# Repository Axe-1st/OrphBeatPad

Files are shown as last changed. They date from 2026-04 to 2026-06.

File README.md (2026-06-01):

# OrphBeatPad - A custom/open source Beat pad with awesome design!
## V2 IS OUT!! 
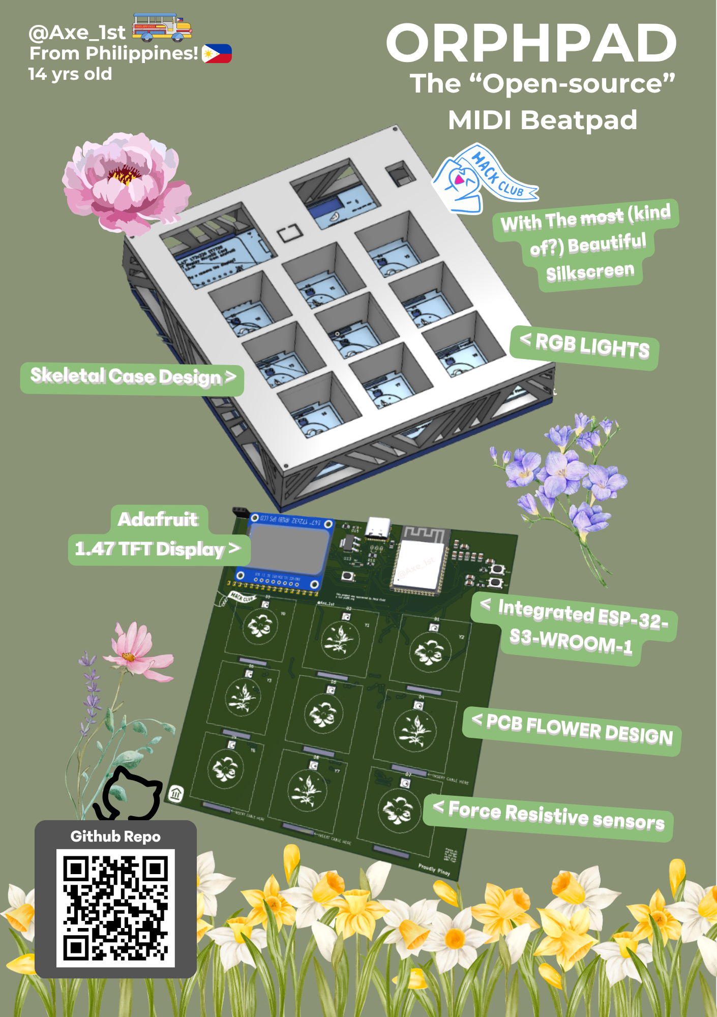
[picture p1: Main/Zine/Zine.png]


> PDF is available in Zine folder!

#### I wanted to make an custom beat pad that you can plug in into your computer and its good to go!
#### I would say the motivation was discovering FRS Sensors and bc i love hardware too much.
#### It Exists since i want to get started with making MIDI Stuff and see how much it can cost!
#### This project is basicaly a beat pad that can sense how hard are you tapping the pads and, BUT the most special part about this is it has integrated esp32-s3-wroom 1 🫣

#### Notes:
- The FSR Sensors Does not use a breakout board!
- There are Silicon pads that i will have to invividualy place to act as buttons!
- we will be ussing flush cutters so we can fit things nicely!
- We will use a combination of reflow and manual soldering.

### Schematic

#### New Schematic


### PCB 
#### look at that pcb 🤤

#### New PCB Design


### "pcb render"

#### New Version



- couldn't find a FSR sensor thats bent sorry!

### CAD


### Onshape Link https://cad.onshape.com/documents/ce0d6d23ca34879564001471/w/3b900ad8676028993156f6d1/e/086cec854ef049c97401a80d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

#### i love onshape man

## How to build it
### a project thats been wating to be funded so it will relese soon!
#### But don't worry i can give you a rough idea how to make it!

- Step 1 Make sure all of your materials are ready such as (PCB, Stencil, Compoments, Hot Plate, 3D printed Case) if not don't worry as you can buy the compoments online from digikey and Jlcpcb! Check the BOM cause it has links!

- Step 2 Align the Stencil and spread solder Paste

- Step 3 Gently remove the stencil then place all of your compoments to reflow it at the hot plate! (you can use a soldering iron if you think you can do it!) a little tip when placing start from smallest to biggest!\

- Step 4 Reflow the board by making sure that the esp32 is in the middle! 

- Step 5 Now the Reflow is done start adding the compoments that need manual hand soldering, such as: Sk-mini-e, 16 channel Swicher, FSR sensor pads.

- Step 6 Your PCB is assembled! Final step is to assemble with the case! To assemble the case (3 parts) get the bottom and middle super glue it, then after drying place the pcb inside, also make sure the external pins are cut with a flush cutter! Add the top case then superglue it or Use any M4 thread screw.

- Step 7 Cut the Silicon Sheet into squares boxes then place it where the FSR Sensor holes are!

- Final step is to Plug in the USB C cable and hope no smoke comes out.. If none good job! Flash it with the firmware i have provided :)

- And thats your own OrphBeatpad! Enjoy tinkering with it!!

## Bill of materials
### check Bom.csv

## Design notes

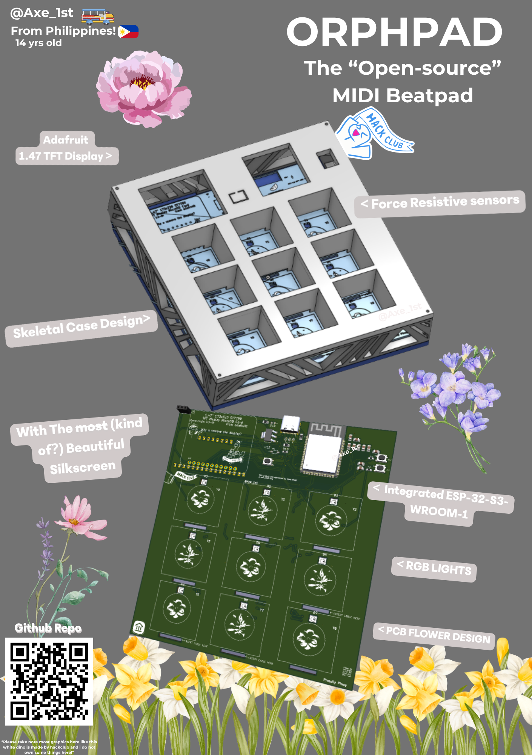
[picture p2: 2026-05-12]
Main/Zine/Orphpad Zine final (1).png

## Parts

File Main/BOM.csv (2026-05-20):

Product | Link | Quantity | Price USD | total
ESP32-S3-WROOM-1 | https://jlcpcb.com/partdetail/3198295-ESP32_S3_WROOM_1N4/C2913197 | 1 | $4.49 | $4.49
Silicon sheet | Translucent Silicone Rubber Sheet Plate Mat High Temperature Resistant Clear Gasket Thick 0.5 1 2 3 4 5mm | Shopee Philippines | 1 | $1.64 | $1.64
LESD5D5.0CT1G | https://jlcpcb.com/partdetail/LRC-LESD5D50CT1G/C383211 | 10 | $0.40 | $4.00
1N5819HW-7-F | https://jlcpcb.com/partdetail/DiodesIncorporated-1N5819HW_7F/C82544 | 2 | $0.04 | $0.08
FSR Sensors | https://shopee.ph/FSR402-RFP602-Resistive-Thin-Film-Pressure-Sensor-Module-Force-Sensitive-Resistor-Board-RFP602-1KG-2KG-5KG-Weighing-Voltage-Conversion-Modul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 | 1 | $19.62 | $19.62
16 channel switcher | https://shopee.ph/CD74HC4067-16-Channel-Analog-Digital-Multiplexer-Breakout-Board-Module-For-Arduino-i.266699902.22751563093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 | 1 | $1.07 | $1.07
SK-Mini-e | https://jlcpcb.com/partdetail/OPSCOOptoelectronics-SK6812MINIE/C5149201 | 20 | $0.09 | $1.80
C2912598 | https://jlcpcb.com/partdetail/C2912598 | 5 | $0.08 | $0.40
Resistor | https://jlcpcb.com/partdetail/RESI-PTFR0805B200RP9/C2849095 | 5 | $0.07 | $0.35
Type C female | https://jlcpcb.com/parts/componentSearch?searchTxt=C2765186 | 1 | $0.09 | $0.09
JLCPCB | JLCPCB | 1 | $9.50 | $9.50
10uf cap | https://www.digikey.ph/en/products/detail/samsung-electro-mechanics/CL21A106KAYNNNG/3894413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 | 10 | $0.09 | $0.89
1uf capacitor | https://www.digikey.ph/en/products/detail/samsung-electro-mechanics/CL10A105KO8NNNC/3886692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 | 5 | $0.10 | $0.50
10 ohm resistor | https://www.digikey.ph/en/products/detail/stackpole-electronics-inc/RNCP0603FTD10K0/2240139 | 10 | $0.01 | $0.12
CAP CER 0.1UF 50V X7R 0603 | https://www.digikey.ph/en/products/detail/samsung-electro-mechanics/CL10B104KB8NNNL/3894274 | 12 | $0.03 | $0.32
4518-AMS1117-3.3TR-ND | https://www.digikey.ph/en/products/detail/umw/AMS1117-3-3/17635254 | 3 | $0.30 | $0.90
399-C0603C220J5GAC7867TR-ND | https://www.digikey.ph/en/products/detail/kemet/C0603C220J5GACTU/411055 | 3 | $0.13 | $0.39
smd Buttons | https://www.digikey.ph/en/products/detail/c-k/PTS810SJG250SMTR-LFS/4176612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 | 6 | $0.60 | $3.60
Pwr led | https://www.digikey.ph/en/products/detail/liteon/LTST-C190TBKT/388529?s=N4IgTCBcDaIIwDYAMBaRAWBKwoHIBEQBdAXyA | 2 | $0.17 | $0.34
Soldering hot plate | https://shopee.ph/G3061-PD65W-Mini-Hot-Plate-Digital-Soldering-Preheating-Rework-Station-PCB-SMD-Board-Soldering-Plate-Heating-Table-i.1118934132.29593809780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 | 1 | $11.46 | $11.46
Adafruit 1.47 tft | https://www.digikey.ph/en/products/detail/adafruit-industries-llc/5393/16129670 | 1 | $17.50 | $17.50
Stencil | JLCPCB | 1 | $7.90 | $7.90
 |  |  |  | TOTAL
 |  |  |  | $86.96

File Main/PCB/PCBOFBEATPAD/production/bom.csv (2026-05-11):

Designator | Footprint | Quantity | Value | LCSC Part #
C1, C2, C4, C9 | 0805 | 4 | 10uF
C10 | 0805 | 1 | 1uF
C3, C5, C6, C7, C8 | 0805 | 5 | 0u1F
D1, D2, D3, D4, D5, D6, D7, D8, D9 | SK6812MINI-E_fixed | 9 | SK6812MINI-E
D10, D12, D13 | TVS_LESD5D5.0CT1G | 3 | LESD5D5.0CT1G
D11 | SOD3715X145N | 1 | 1N5819HW-7-F
D15 | LEDC1608X35N | 1 | LTST-C190KGKT
J1 | HRO_TYPE-C-31-M-12 | 1 | TYPE-C-31-M-12
J3 | PinSocket_1x03_P2.00mm_Vertical | 1 | Conn_01x03
JP1 | 1X11_ROUND_76 | 1 | ~
R1, R10, R13, R14, R15, R2, R3, R4, R5, R6, R7, R8 | 0603 | 12 | 10k
R11, R9 | 0805 | 2 | 5k1
R12 | 0805 | 1 | 75
SW1, SW2, SW3 | SW_PTS810_SJM_250_SMTR_LFS | 3 | PTS810_SJM_250_SMTR_LFS
U1, U10, U11, U3, U5, U6, U7, U8, U9 | 2 pin connector | 9 | ~
U12 | XCVR_ESP32-S3-WROOM-1-N16R2 | 1 | ESP32-S3-WROOM-1-N16R2
U13 | SOT229P700X180-4N | 1 | AMS1117-3.3
U2 | analog_16_multiplexer_module | 1 | ~

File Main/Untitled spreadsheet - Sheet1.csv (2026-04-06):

Product | Link | Price PHP | Price USD | Current USD Price
ESP32-C3 DEVBOARD | https://shopee.ph/ESP32-SuperMini-Development-Board-ESP32-C3-ESP32-S3-ESP32-C6-ESP32-H2-Development-Board-ESP32-Development-Board-WiFi- | $130.00 | $2.15 | 60.41
Silicon sheet | Translucent Silicone Rubber Sheet Plate Mat High Temperature Resistant Clear Gasket Thick 0.5 1 2 3 4 5mm | Shopee Philippines | $100.00 | $1.66 | 60.41
SK MINI 6812 1 SET | https://shopee.ph/10PCS-SK6812-MINI-E-RGB-(Similar-WS2812B)-SK6812-3228-SMD-Pixels-LED-Chip-Individually-Addressable-i.672422012.12275127933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 | $30.00 | $0.50 | 60.41
Connector | https://shopee.ph/2.54MM-R-A-Double-Row-Female-2~40P-PCB-Board-Right-Angle-Pin-Header-Socket-Connector-Pinheader-2*-4-6-10-20-40-Pin-For-Arduino-i.1130255612.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 | $69.00 | $1.14 | 60.41
Force resistive sensors | https://shopee.ph/FSR402-RFP602-Resistive-Thin-Film-Pressure-Sensor-Module-Force-Sensitive-Resistor-Board-RFP602-1KG-2KG-5KG-Weighing-Voltage-Conversion-Modul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 | $1,197.00 | $19.81 | 60.41
16 channel switcher | https://shopee.ph/CD74HC4067-16-Channel-Analog-Digital-Multiplexer-Breakout-Board-Module-For-Arduino-i.266699902.22751563093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 | $65.00 | $1.08 | 60.41
1.3 tft | https://shopee.ph/TFT-Display-0.96-1.3-1.44-Inch-IPS-7P-SPI-HD-65K-Full-Color-LCD-Module-ST7735-Drive-IC-80*160-(Not-OLED)-For-Arduino-i.580325202.13990205071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 | $128.00 | $2.12 | 60.41
JLCPCB |  | $0.00 | $5 | 60.41
 |  | $0.00 | $0.00 | 60.41
 |  | $0.00 | $0.00 | 60.41
 |  | $0.00 | $0.00 | 60.41

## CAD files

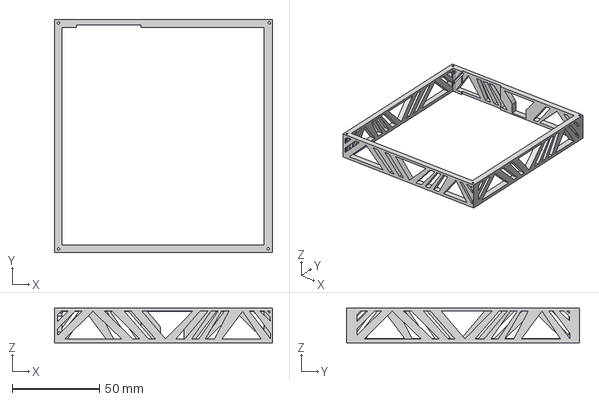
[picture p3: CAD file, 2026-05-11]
Main/CAD/Middle.step
124.7 x 133.4 x 20.0 mm

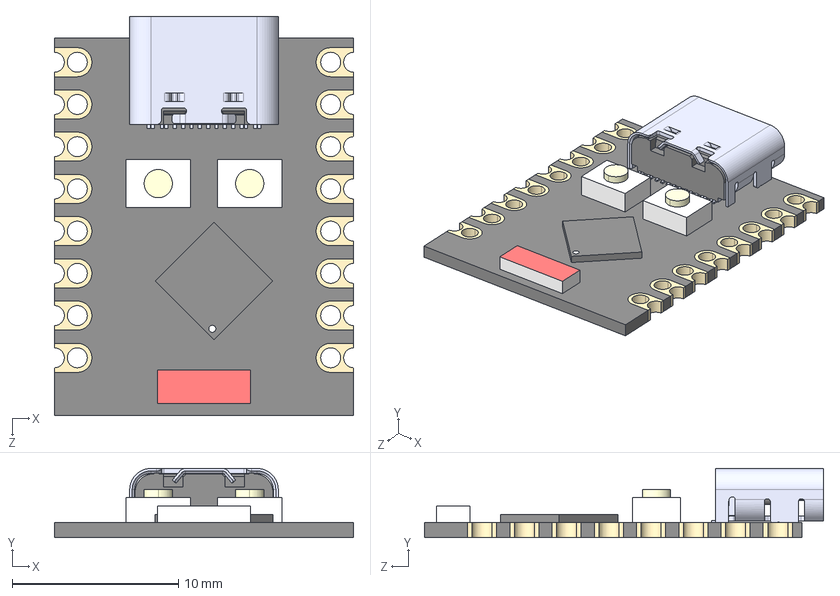
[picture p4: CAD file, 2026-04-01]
Main/EXTRAS/ESP32-C3_SUPERMINI_TH/ESP32-C3_SUPERMINI_TH.step
18.0 x 4.16 x 24.0 mm
Board c3mini
USB C
components (other)^ESP32-C3 SuperMini

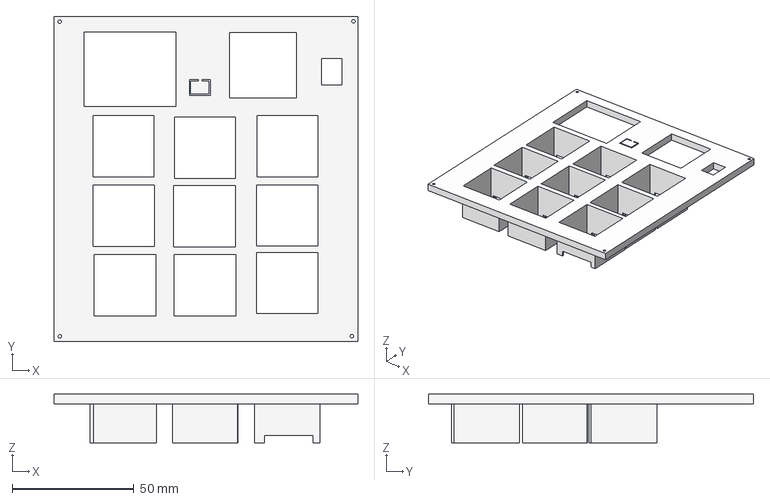
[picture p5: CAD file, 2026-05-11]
Main/CAD/Top.step
124.7 x 133.4 x 20.0 mm

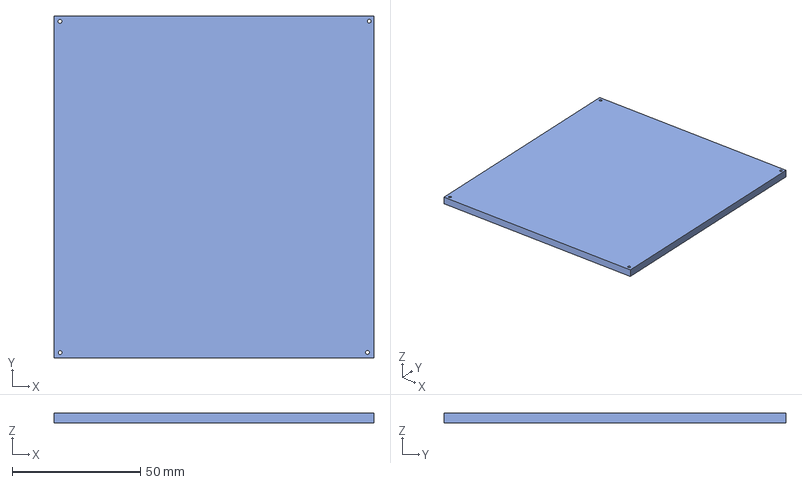
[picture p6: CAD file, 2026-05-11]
Production/Bottom.step
124.7 x 133.4 x 4.00 mm

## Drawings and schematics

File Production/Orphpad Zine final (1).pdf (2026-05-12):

# The “Open-source” MIDI Beatpad

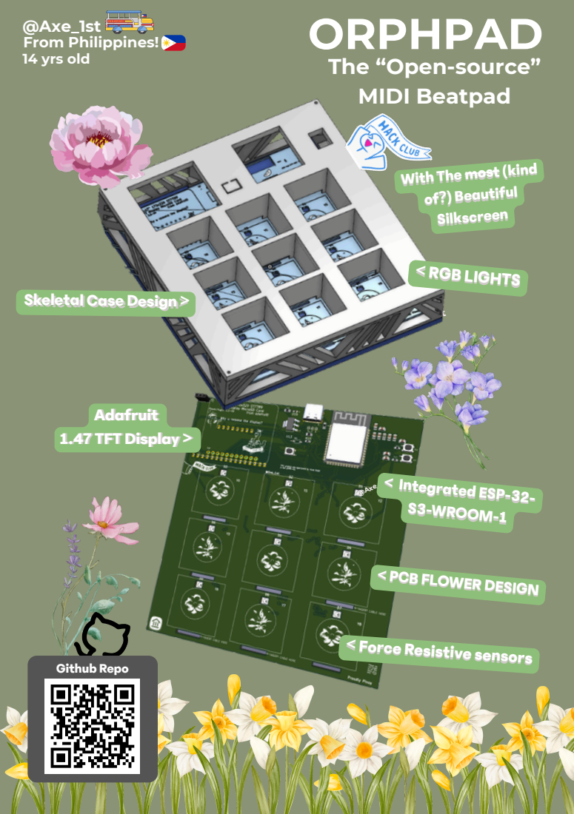
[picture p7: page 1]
@Axe_; @Axe_1st; ORPHPAD; From Philippines! 14 yrs old; Github Repo; Adafruit 1.47 TFT Display >; SSkkeelleettaallCCaasseeDDeessiiggnn>>; of?) Beautiful; Silkscreen; < Integrated ESP-32-; S3-WROOM-1; < RGB LIGHTS

With The most (kind

< PCB FLOWER DESIGN

< Force Resistive sensors

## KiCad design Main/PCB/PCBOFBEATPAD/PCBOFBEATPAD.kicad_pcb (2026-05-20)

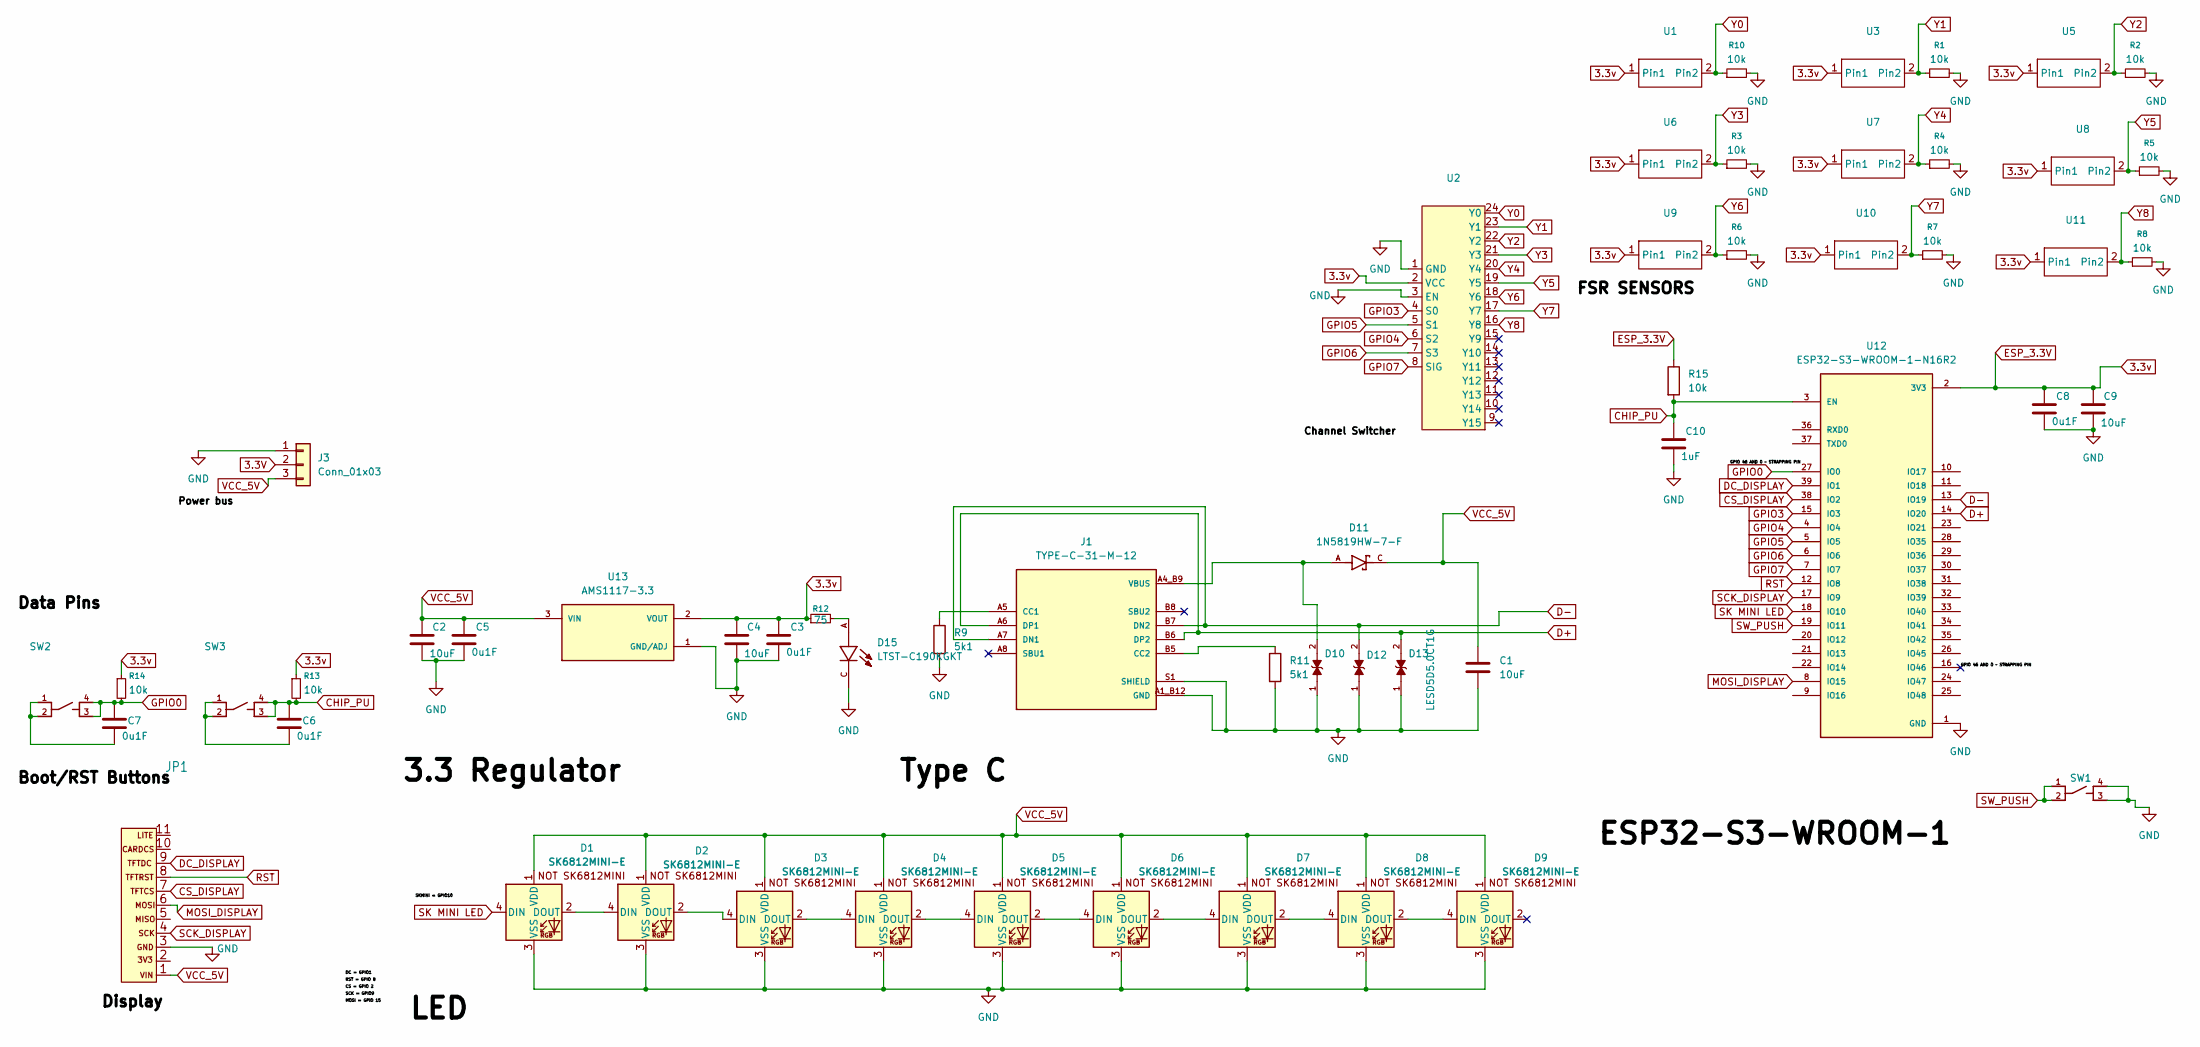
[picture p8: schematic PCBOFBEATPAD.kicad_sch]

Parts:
C1, C2, C4, C9: 10uF; C_0805_2012Metric_Pad1.18x1.45mm_HandSolder
C3, C5, C6, C7, C8: 0u1F; C_0805_2012Metric_Pad1.18x1.45mm_HandSolder
C10: 1uF; C_0805_2012Metric_Pad1.18x1.45mm_HandSolder
D1, D2, D3, D4, D5, D6, D7, D8, D9: SK6812MINI-E; SK6812MINI-E_fixed
D10, D12, D13: LESD5D5.0CT1G; TVS_LESD5D5.0CT1G; PARTREV O
D11: 1N5819HW-7-F; SOD3715X145N; PARTREV 18-2
D15: LTST-C190KGKT; LEDC1608X35N
J1: TYPE-C-31-M-12; HRO_TYPE-C-31-M-12; PARTREV 2020.12.08
J3: Conn_01x03; PinSocket_1x03_P2.00mm_Vertical
JP1: 1X11_ROUND_76
R1, R2, R3, R4, R5, R6, R7, R8, R10, R13, R14, R15: 10k; R_0603_1608Metric_Pad0.98x0.95mm_HandSolder
R9, R11: 5k1; R_0805_2012Metric_Pad1.20x1.40mm_HandSolder
R12: 75; R_0805_2012Metric_Pad1.20x1.40mm_HandSolder
SW1, SW2, SW3: PTS810_SJM_250_SMTR_LFS; SW_PTS810_SJM_250_SMTR_LFS
U1, U3, U5, U6, U7, U8, U9, U10, U11: 2 pin connector
U2: analog_16_multiplexer_module
U12: ESP32-S3-WROOM-1-N16R2; XCVR_ESP32-S3-WROOM-1-N16R2; PARTREV v1.0
U13: AMS1117-3.3; SOT229P700X180-4N; PARTREV N/A

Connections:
3.3V: J3.2
3.3v: C3.1, C4.1, C8.1, C9.1, R12.1, R13.1, R14.1, R15.1, U1.1 (Pin1), U2.2 (VCC), U3.1 (Pin1), U5.1 (Pin1), U6.1 (Pin1), U7.1 (Pin1), U8.1 (Pin1), U9.1 (Pin1), U10.1 (Pin1), U11.1 (Pin1), U12.2 (3V3), U13.2 (VOUT)
/GPIO 46 AND 0 ~ STRAPPING PIN: U12.16 (IO46)
CHIP_PU: C6.1, C10.1, R13.2, R15.2, SW3.3, SW3.4, U12.3 (EN)
CS_DISPLAY: JP1.7, U12.38 (IO2)
D+: D13.2, J1.A6 (DP1), J1.B6 (DP2), U12.14 (IO20)
D-: D12.2, J1.A7 (DN1), J1.B7 (DN2), U12.13 (IO19)
DC_DISPLAY: JP1.9, U12.39 (IO1)
GND: C1.2, C2.2, C3.2, C4.2, C5.2, C8.2, C9.2, C10.2, D1.3 (VSS), D2.3 (VSS), D3.3 (VSS), D4.3 (VSS), D5.3 (VSS), D6.3 (VSS), D7.3 (VSS), D8.3 (VSS), D9.3 (VSS), D10.1, D12.1, D13.1, D15.C, J1.A1_B12 (GND), J1.B1_A12 (GND), J1.S1 (SHIELD), J1.S2 (SHIELD), J1.S3 (SHIELD), J1.S4 (SHIELD), J3.1, JP1.3, R1.2, R2.2, R3.2, R4.2, R5.2, R6.2, R7.2, R8.2, R9.2, R10.2, R11.2, SW1.3, SW1.4, U2.1 (GND), U2.3 (EN), U12.1 (GND), U12.40 (GND), U12.41_1 (GND), U12.41_2 (GND), U12.41_3 (GND), U12.41_4 (GND), U12.41_5 (GND), U12.41_6 (GND), U12.41_7 (GND), U12.41_8 (GND), U12.41_9 (GND), U13.1 (GND/ADJ)
GPIO0: C7.1, R14.2, SW2.3, SW2.4, U12.27 (IO0)
GPIO3: U2.4 (S0), U12.15 (IO3)
GPIO4: U2.6 (S2), U12.4 (IO4)
GPIO5: U2.5 (S1), U12.5 (IO5)
GPIO6: U2.7 (S3), U12.6 (IO6)
GPIO7: U2.8 (SIG), U12.7 (IO7)
MOSI_DISPLAY: JP1.6, U12.8 (IO15)
unnamed: C6.2, SW3.1, SW3.2
unnamed: C7.2, SW2.1, SW2.2
unnamed: D1.2 (DOUT), D2.4 (DIN)
unnamed: D2.2 (DOUT), D3.4 (DIN)
unnamed: D3.2 (DOUT), D4.4 (DIN)
unnamed: D4.2 (DOUT), D5.4 (DIN)
unnamed: D5.2 (DOUT), D6.4 (DIN)
unnamed: D6.2 (DOUT), D7.4 (DIN)
unnamed: D7.2 (DOUT), D8.4 (DIN)
unnamed: D8.2 (DOUT), D9.4 (DIN)
unnamed: D15.A, R12.2
unnamed: J1.A5 (CC1), R9.1
unnamed: J1.B5 (CC2), R11.1
RST: JP1.8, U12.12 (IO8)
SCK_DISPLAY: JP1.4, U12.17 (IO9)
SK MINI LED: D1.4 (DIN), U12.18 (IO10)
SW_PUSH: SW1.1, SW1.2, U12.19 (IO11)
VBUS: D10.2, D11.A, J1.A4_B9 (VBUS), J1.B4_A9 (VBUS)
VCC_5V: C1.1, C2.1, C5.1, D1.1 (VDD), D2.1 (VDD), D3.1 (VDD), D4.1 (VDD), D5.1 (VDD), D6.1 (VDD), D7.1 (VDD), D8.1 (VDD), D9.1 (VDD), D11.C, J3.3, JP1.1, U13.3 (VIN)
Y0: R10.1, U1.2 (Pin2), U2.24 (Y0)
Y1: R1.1, U2.23 (Y1), U3.2 (Pin2)
Y2: R2.1, U2.22 (Y2), U5.2 (Pin2)
Y3: R3.1, U2.21 (Y3), U6.2 (Pin2)
Y4: R4.1, U2.20 (Y4), U7.2 (Pin2)
Y5: R5.1, U2.19 (Y5), U8.2 (Pin2)
Y6: R6.1, U2.18 (Y6), U9.2 (Pin2)
Y7: R7.1, U2.17 (Y7), U10.2 (Pin2)
Y8: R8.1, U2.16 (Y8), U11.2 (Pin2)

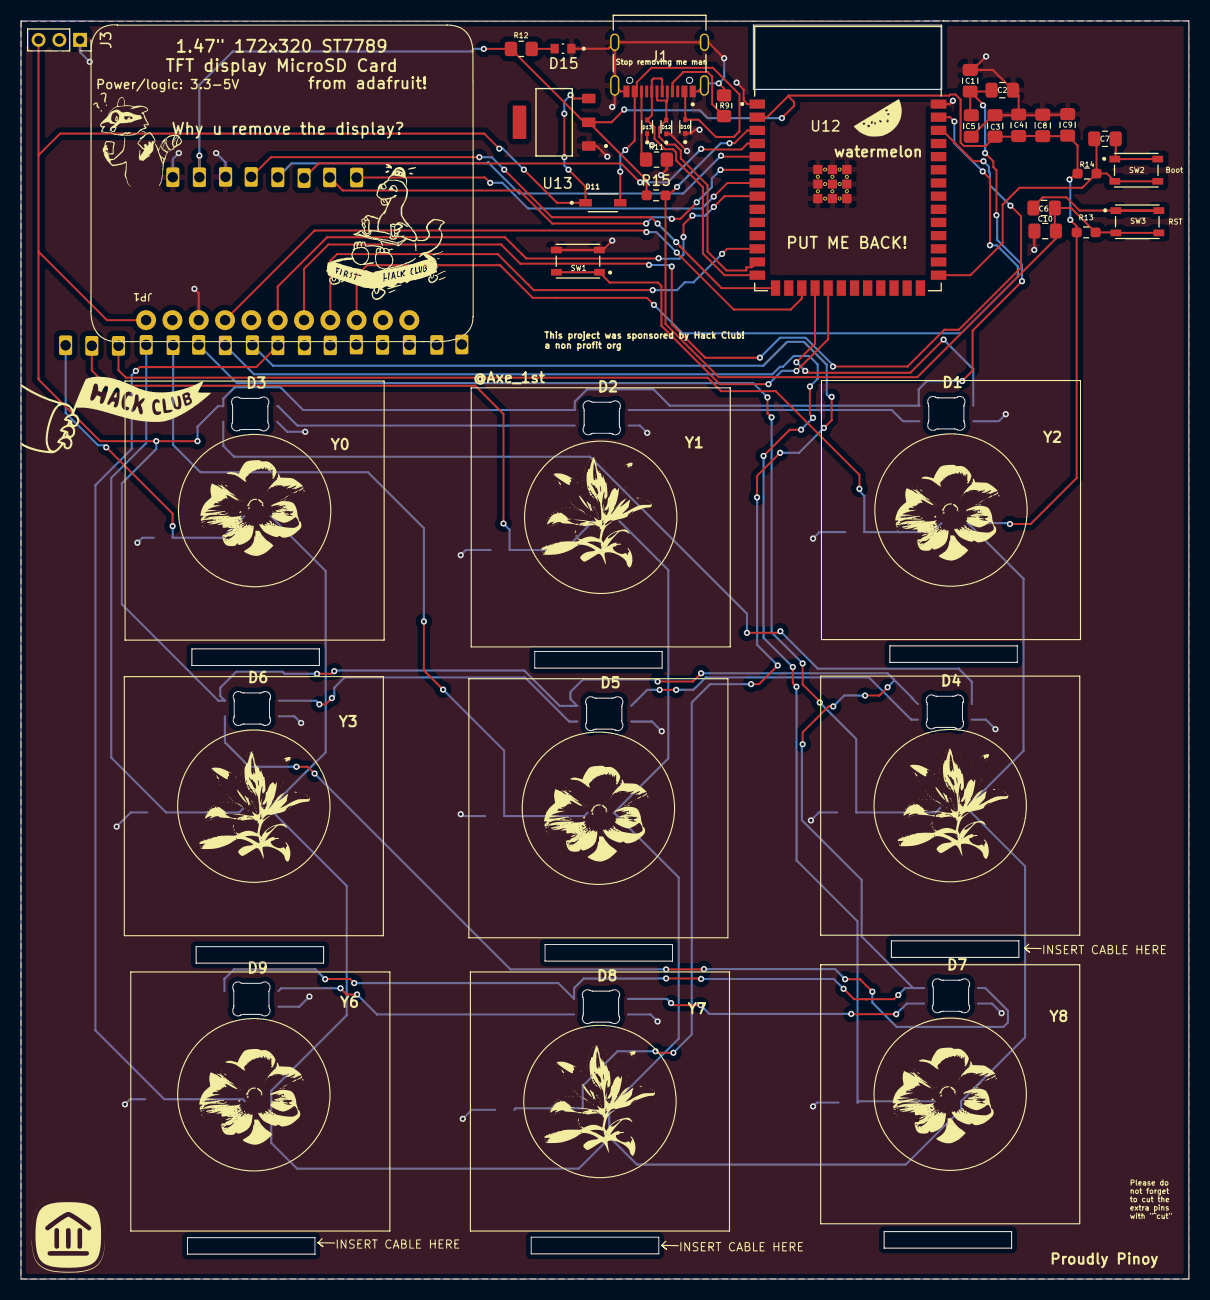
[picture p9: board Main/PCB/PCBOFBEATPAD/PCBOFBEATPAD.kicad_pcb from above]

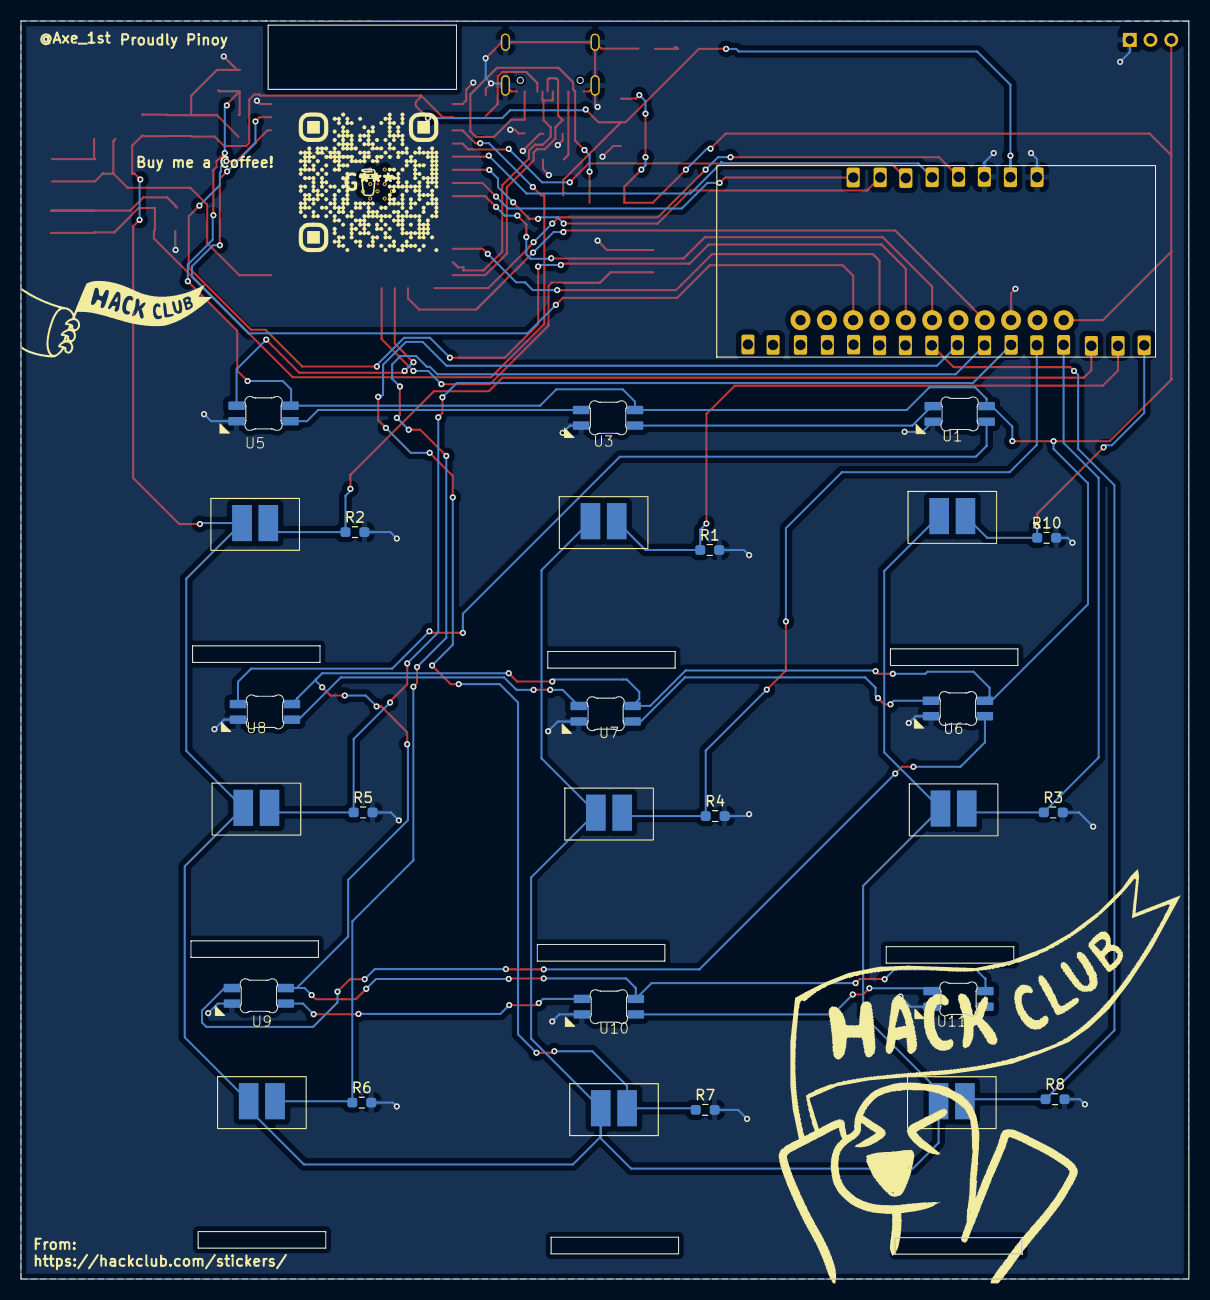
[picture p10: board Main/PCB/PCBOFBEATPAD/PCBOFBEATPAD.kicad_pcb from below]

Board: 2 copper layers, 112.7 x 121.4 mm, 57 parts (19 on the bottom side), 42 nets.

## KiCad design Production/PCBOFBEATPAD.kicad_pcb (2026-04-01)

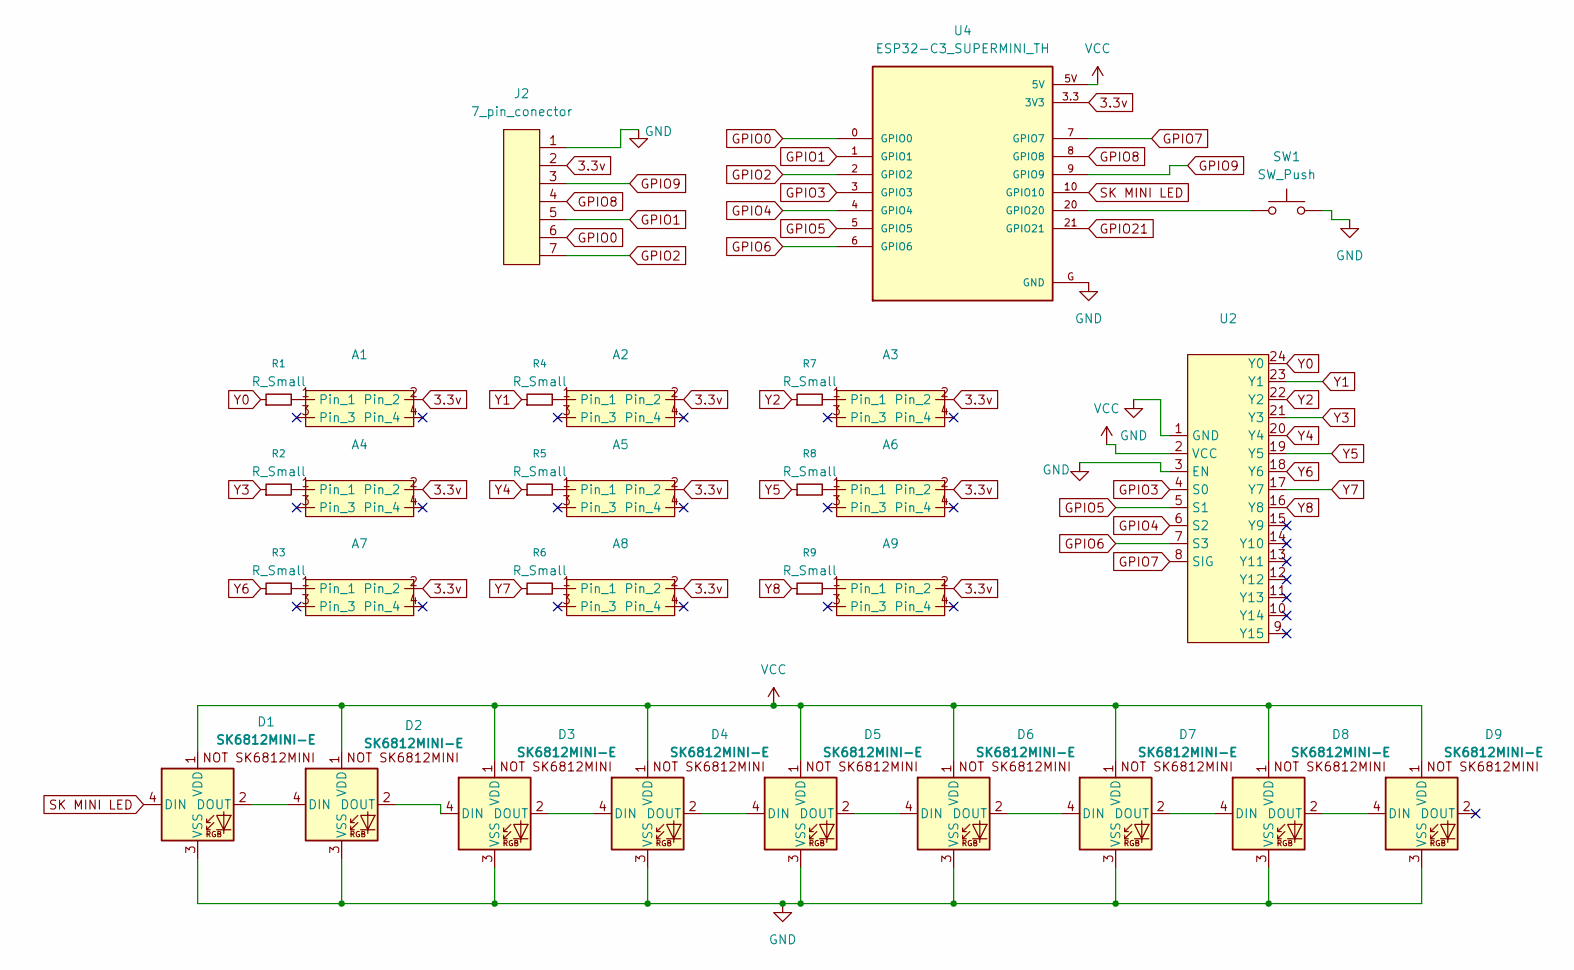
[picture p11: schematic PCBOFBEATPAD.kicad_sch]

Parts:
A1, A2, A3, A4, A5, A6, A7, A8, A9: 2x2 connectorss
D1, D2, D3, D4, D5, D6, D7, D8, D9: SK6812MINI-E; SK6812MINI-E_fixed
J2: 7_pin_conector; 1.3 tft display
R1, R2, R3, R4, R5, R6, R7, R8, R9: R_Small; R_Axial_DIN0204_L3.6mm_D1.6mm_P5.08mm_Horizontal
SW1: SW_Push; SW_PUSH_6mm
U2: analog_16_multiplexer_module
U4: ESP32-C3_SUPERMINI_TH; MODULE_ESP32-C3_SUPERMINI_TH

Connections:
3.3v: A1.2, A2.2, A3.2, A4.2, A5.2, A6.2, A7.2, A8.2, A9.2, J2.2, U4.3.3 (3V3)
GND: D1.3 (VSS), D2.3 (VSS), D3.3 (VSS), D4.3 (VSS), D5.3 (VSS), D6.3 (VSS), D7.3 (VSS), D8.3 (VSS), D9.3 (VSS), J2.1 (GND), SW1.2, U2.1 (GND), U2.3 (EN), U4.G (GND)
GPIO0: J2.6, U4.0 (GPIO0)
GPIO1: J2.5, U4.1 (GPIO1)
GPIO2: J2.7, U4.2 (GPIO2)
GPIO3: U2.4 (S0), U4.3 (GPIO3)
GPIO4: U2.6 (S2), U4.4 (GPIO4)
GPIO5: U2.5 (S1), U4.5 (GPIO5)
GPIO6: U2.7 (S3), U4.6 (GPIO6)
GPIO7: U2.8 (SIG), U4.7 (GPIO7)
GPIO8: J2.4, U4.8 (GPIO8)
GPIO9: J2.3, U4.9 (GPIO9)
GPIO21: U4.21 (GPIO21)
unnamed: A1.1, R1.2
unnamed: A2.1, R4.2
unnamed: A3.1, R7.2
unnamed: A4.1, R2.2
unnamed: A5.1, R5.2
unnamed: A6.1, R8.2
unnamed: A7.1, R3.2
unnamed: A8.1, R6.2
unnamed: A9.1, R9.2
unnamed: D1.2 (DOUT), D2.4 (DIN)
unnamed: D2.2 (DOUT), D3.4 (DIN)
unnamed: D3.2 (DOUT), D4.4 (DIN)
unnamed: D4.2 (DOUT), D5.4 (DIN)
unnamed: D5.2 (DOUT), D6.4 (DIN)
unnamed: D6.2 (DOUT), D7.4 (DIN)
unnamed: D7.2 (DOUT), D8.4 (DIN)
unnamed: D8.2 (DOUT), D9.4 (DIN)
unnamed: SW1.1, U4.20 (GPIO20)
SK MINI LED: D1.4 (DIN), U4.10 (GPIO10)
VCC: D1.1 (VDD), D2.1 (VDD), D3.1 (VDD), D4.1 (VDD), D5.1 (VDD), D6.1 (VDD), D7.1 (VDD), D8.1 (VDD), D9.1 (VDD), U2.2 (VCC), U4.5V
Y0: R1.1, U2.24 (Y0)
Y1: R4.1, U2.23 (Y1)
Y2: R7.1, U2.22 (Y2)
Y3: R2.1, U2.21 (Y3)
Y4: R5.1, U2.20 (Y4)
Y5: R8.1, U2.19 (Y5)
Y6: R3.1, U2.18 (Y6)
Y7: R6.1, U2.17 (Y7)
Y8: R9.1, U2.16 (Y8)

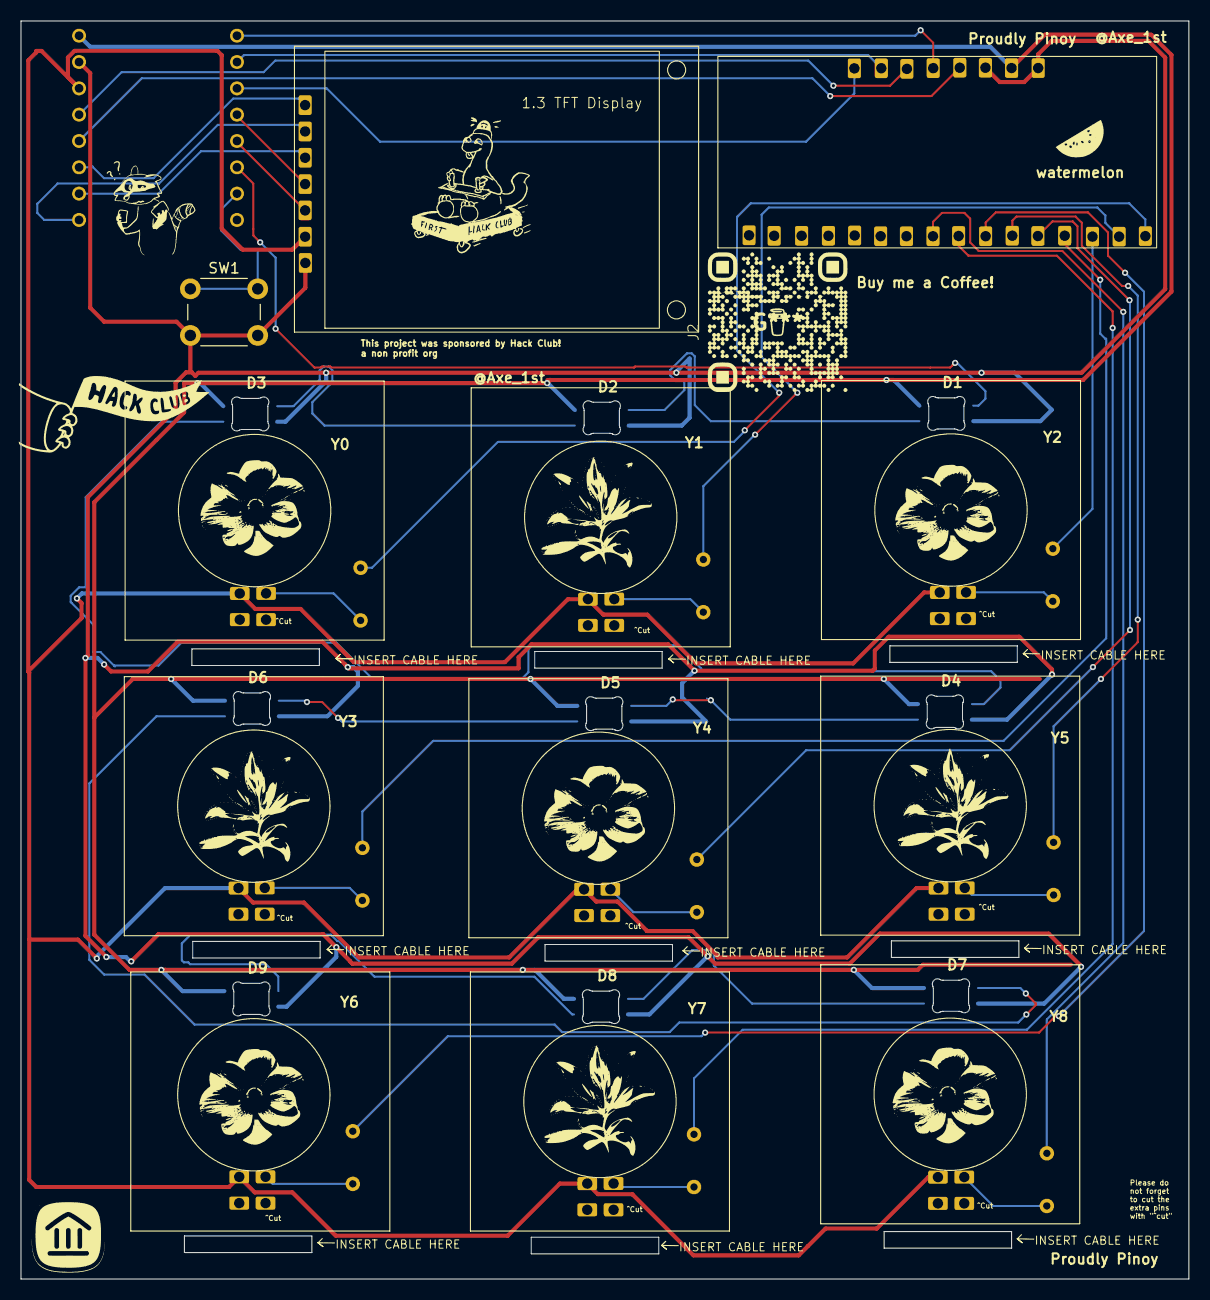
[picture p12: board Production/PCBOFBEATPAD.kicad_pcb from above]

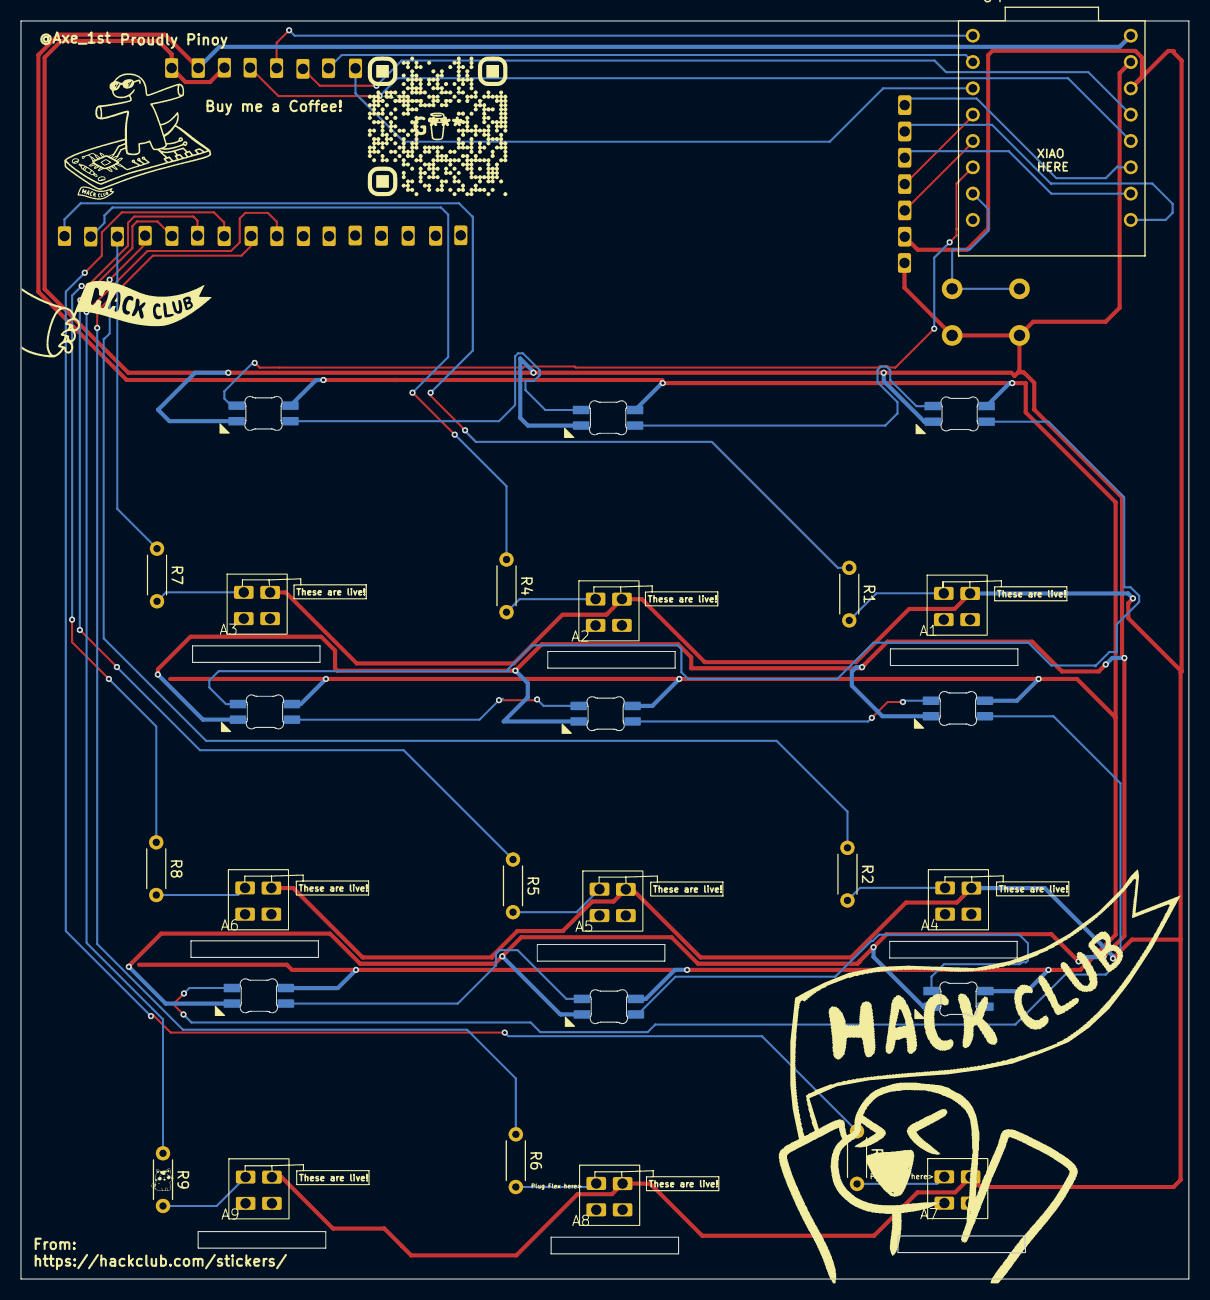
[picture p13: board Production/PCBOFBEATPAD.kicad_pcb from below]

Board: 2 copper layers, 112.7 x 121.4 mm, 31 parts (19 on the bottom side), 41 nets.

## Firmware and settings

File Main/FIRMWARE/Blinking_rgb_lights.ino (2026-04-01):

#include <Adafruit_NeoPixel.h>
#define LED_PIN  4 
#define NUM_LEDS 2
Adafruit_NeoPixel strip(NUM_LEDS, LED_PIN, NEO_GRB + NEO_KHZ800);

void setup() {
strip.begin();
strip.show();
}

void loop() {  ///flash leds
strip.fill(strip.Color(255, 255, 255));
strip.show();
delay(350);
strip.clear();
strip.show();
delay(350);
}

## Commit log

2026-04-01 Added bom
2026-04-01 Adding Files to Github
    No Zine in this Version yet
    [BOTTOM OF ORPHPAD V1.stl, ESP32-C3_SUPERMINI_TH.step, PCBOFBEATPAD.kicad_pcb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]
2026-04-06 bom update
2026-04-06 Add Bill of Materials with component details
2026-04-06 Added cad to main
    [BOTTOM OF ORPHPAD V1.stl, PCBOFBEATPAD.step, TOP OF ORPHPAD V1.stl]
2026-04-06 i hate ai checker slop
    [BOTTOM OF ORPHPAD V1.stl, PCBOFBEATPAD.step, TOP OF ORPHPAD V1.stl]
2026-04-06 Add CSV
    [Untitled spreadsheet - Sheet1.csv]
2026-04-06 CSV of CSV
    [Untitled spreadsheet - Sheet1 (1).csv, Untitled spreadsheet - Sheet1.csv]
2026-04-06 Zine Fix
    [BOM.csv]
2026-05-08 Updated Readme
    OMDD the USB cad was flipped
2026-05-11 Added Onshape link and Cad image
2026-05-11 Major Update (V2 RELEASE)
    [BOTTOM OF ORPHPAD V1.stl, Bottom.stl, Middle.stl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]
2026-05-11 V2 final Commit
    [BOM.csv]
2026-05-11 v2 update
    [BOM.csv, PCBOFBEATPAD.csv, PCBOFBEATPADcopy1.kicad_pcb]
2026-05-11 Organized Repo
    [Bottom.step, Bottom.stl, Middle.step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]
2026-05-12 zine ahh update
    [PCBOFBEATPAD.kicad_sch]
2026-05-20 Update images in README for pcb render section
    Updated image dimensions and replaced an old image with a new one in the README.
2026-06-01 Update README with additional assembly instructions
    Added note about cutting silicon sheet for FSR sensors.
